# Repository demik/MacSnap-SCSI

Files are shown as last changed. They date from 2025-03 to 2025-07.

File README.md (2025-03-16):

# MacSnap SCSI

The MacSnap SCSI is an upgrade for the Macintosh 512K(e) It includes a SCSI controller and is designed to plug into the ROM slots
It was developed by Dove Computer Corporation. This is a REcreation with a few improvements.

<br />
<br />
<div align = center>
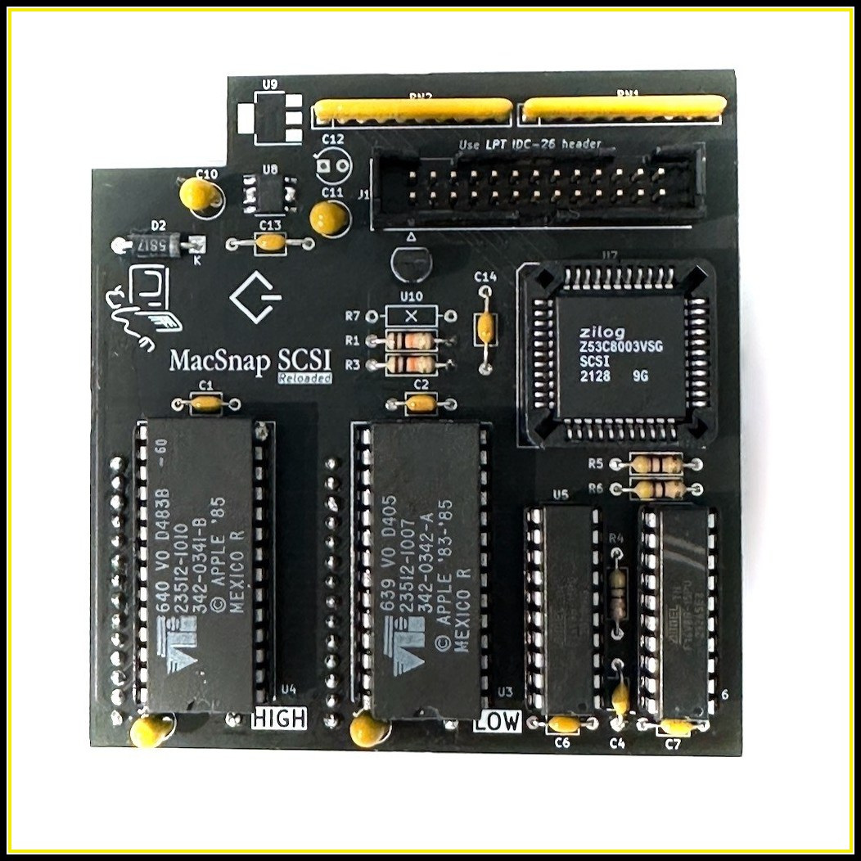
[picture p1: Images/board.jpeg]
board
	
</div>

<br />
<br />
<br />
<br />

## [][Documentation]
- Kikad Files are located [here](EDA/REloaded), as well with building instructions for the REloaded board
- PLD files are located [here](PLD)
- Gerbers files are in the [release section](https://github.com/demik/MacSnap-SCSI/releases/download/v2.1/MacSnap_SCSI_Reloaded_2.1.zip)
- Schematic in PDF form is [here](https://github.com/demik/MacSnap-SCSI/blob/main/EDA/REloaded/MacSnap%20SCSI.pdf)

<!----------------------------------------------------------------------------->

[Documentation]: https://github.com/demik/MacSnap-SCSI/tree/main/EDA/REloaded/README.md

<!-------------------------------[ Buttons ]----------------------------------->

[Button Documentation]: https://img.shields.io/badge/Documentation-FFDD21?style=for-the-badge&logoColor=white&logo=opensourcehardware

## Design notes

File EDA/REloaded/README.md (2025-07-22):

# MacSnap SCSI Reloaded

This is a simple design clone to the original, using mostly all through hole components. It's designed this way to be period correct and easy to build for people who don't like soldering SMD components. The only SMD component is the 2.85V voltage regulator for SCSI termination.
Footprint is very similar. Like the original, the SCSI is provided through a LPT header.

The board has a few improvements:
- provides power to SCSI devices
- active SCSI termination
- voltage supervisor / reset ciruit

This folder contains the source KiKad files for this board.

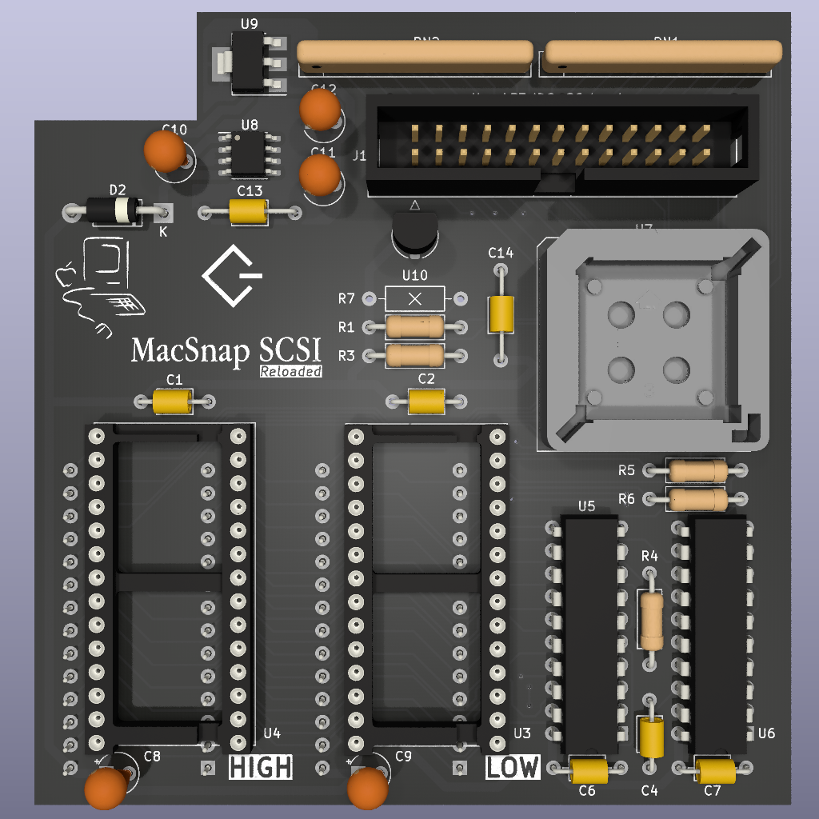
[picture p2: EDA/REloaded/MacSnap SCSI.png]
PCB


## 
### Mandatory

Here is the BOM for the board. Part number are what was tested on prototypes board but you may find alternatives easily, especially resistors and sockets

| Reference(s) | Value | Quantity | Notes | Part number |
|---|---|---|---|---|
| C1-2, C6, C7, C13-14  | 100nF | 6 | Axial ceramic capacitor X7R | Kemet C412C104K5R5TA7200 |
| C4 | 1500pF | 1 | Axial ceramic capacitor X7R 10% | Kemet C410C152K1R5TA |
| C8-11 | 10uF | 4 | Tantalum radial capacitor 2.5mm pitch  | Thomsen 481726 |
| D2 | 1N5817 | 1 | Schottky Diode DO-15 20V | Diotec 1N5817 |
| J1 | 26 pins | 1 | low profile shrouded IDC header | TE Conn 5103309-6 |
| R1, R3 | 10kΩ | 2 | standard 0.25W carbon film resistor | TRU CFR0W4J0103 |
| R4 | 470Ω | 1 | standard 0.25W carbon film resistor | TRU CFR0W4J0471 |
| R5, R6 | 47Ω | 2 | standard 0.25W carbon film resistor | TRU CFR0W4J0470 |
| RN1, RN2 | 110Ω | 2 | 10 pins bussed resistor array | Bourns 4610X-101-111LF |
| U5, U6 | 16V8 | 2 | Programmable Logic Devices 15ns | Microchip ATF16V8B-15PU  |
| U7 | 53C80 | 1 | SCSI Interface IC 3MB/SEC CMOS SCSI I  | Zilog Z53C8003VSG |
| U8 | LDO | 1 | 800mA SCSI-5 Active Terminator | onsemi MC34268DR2G |
| U10 | RESET | 1 | Supervisory Circuits 5V EconoReset | DS1233D-15+ |
| - | LPT | 1 | Parallel DB25 Female LPT to IDC 26-pin | ?? eBay / Amazon |
| - | 14 pins | 4 | Machine Pin break away header | ?? eBay / Amazon |
| Socket | DIP-20 | 2 | THT DIP-20 socket | TRU TC-A 20-LC-TT-203 |
| Socket | DIP-28 | 2 | THT DIP-28 socket | TRU TC-A 28-LC-TT-203 |
| Socket | PLCC-44 | 1 | THT PLCC-44 socket | TRU TC-A-CCS 044-Z-T-203 |

Using sockets is recommended because it will allow you to reclaim both ROMs (to put back into factory) and PLDs

### Alternate

Both the 53C80 SCSI chip and MC34268 are obsolete components. NCR5380 in PLCC package is a working substitute. As for the active terminator LDO, there is an alternate build which consist of the following components:

| Reference(s) | Value | Quantity | Notes | Part number |
|---|---|---|---|---|
| U9 | LDO | 1 | LDO Voltage Regulators 800mA 2.85V | A.D. LT1117CST-2.85 |
| C12 | 10uF | 1 | Tantalum radial capacitor 2.5mm pitch  | Thomsen 481726 |

When the LT1117CST build variant is used, do not populate U8

## 

PCB is 2 layers, the gerbers are avaible in the [release section](https://github.com/demik/MacSnap-SCSI/releases/download/v2.1/MacSnap_SCSI_Reloaded_2.1.zip)
You should be able to use any mainstream PCB manufacturer. Nothing special about this PCB, thickness should be 1.6mm

On JLCPCB, select _Create 2D barcode (Serial Number)_ to the option _Remove Order Number_. Others options to set:
- Printing: 2D barcode Only
- Code Type: QR Code
- Serial Number: MACSNAPSCSI
- QR Code Size: 10mm * 10mm
- QR Code Position: Specify Position

### Assembling

Building is straightworfard. You will need to start with the machine pin headers, then the following order is recommended:
- PDIP sockets
- axial resistors, axial capacitors
- resistors networks
- PLCC socket
- IDC header
- anything else left

### PLDs

You will need the following .jed files to program both ATF with this board:
- [DOV1b](../../PLD/DOV1B.jed) as DOV1b
- [DOV2_low](../../PLD/DOV2_low.jed) as DOV2

A TL866 II or T48 can program ATF16V8Bs just fine. Avoid ATF16V8BQL or ATF16V8C as this has not been tested and might lead into issues

### ROMs

Using real OEM ROMs is recommended. Replica ROMs do have different access timings, source and sink power capabilities, and thus may not work well with the MacSnap SCSI.
The following OEM sets have been tested without issues: 
- 342-0341-B & 342-0342-A
- 342-0341-C + 342-0342-B

<!-------------------------------[ Buttons ]----------------------------------->

[Button BOM]: https://img.shields.io/badge/BOM-FFDD21?style=for-the-badge&logoColor=white&logo=BookStack
[Button Building]: https://img.shields.io/badge/Building-FFDD21?style=for-the-badge&logoColor=white&logo=opensourcehardware

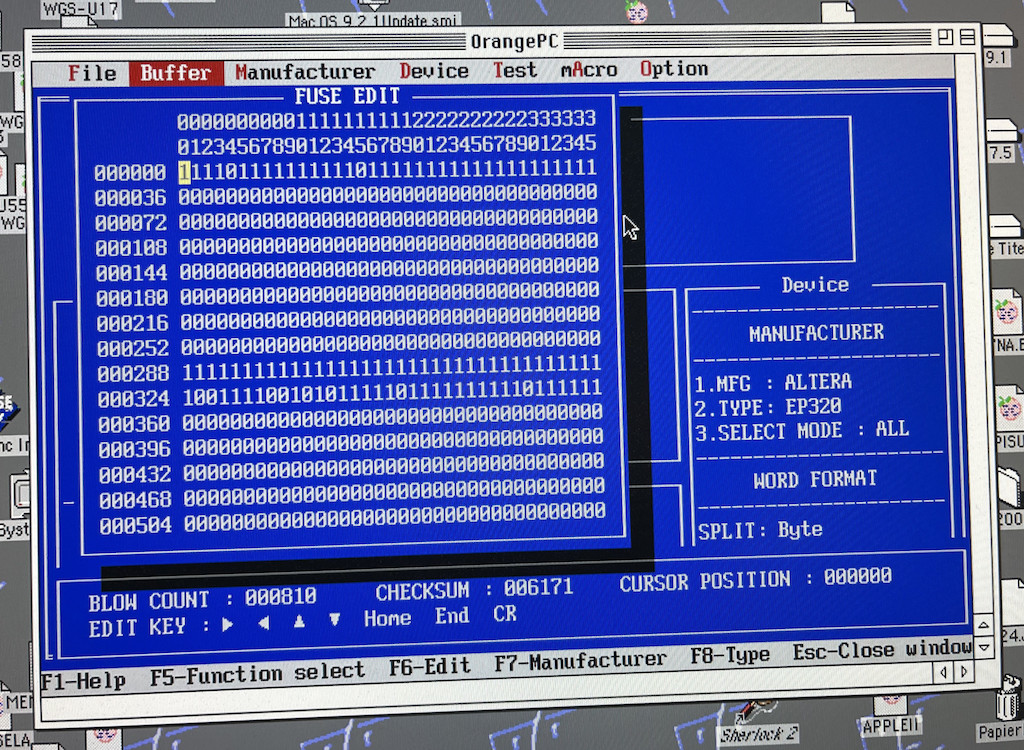
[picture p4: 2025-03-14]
Images/dump.jpeg

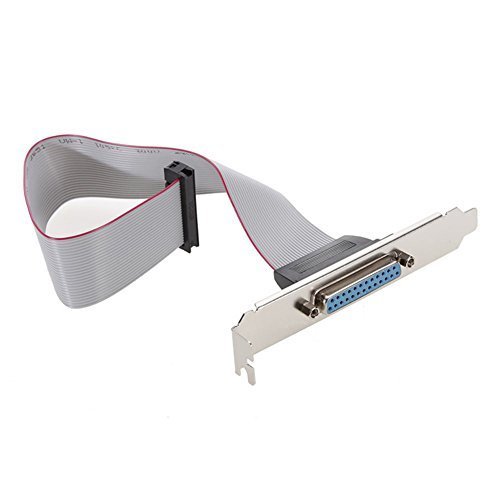
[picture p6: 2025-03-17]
Images/header.jpeg

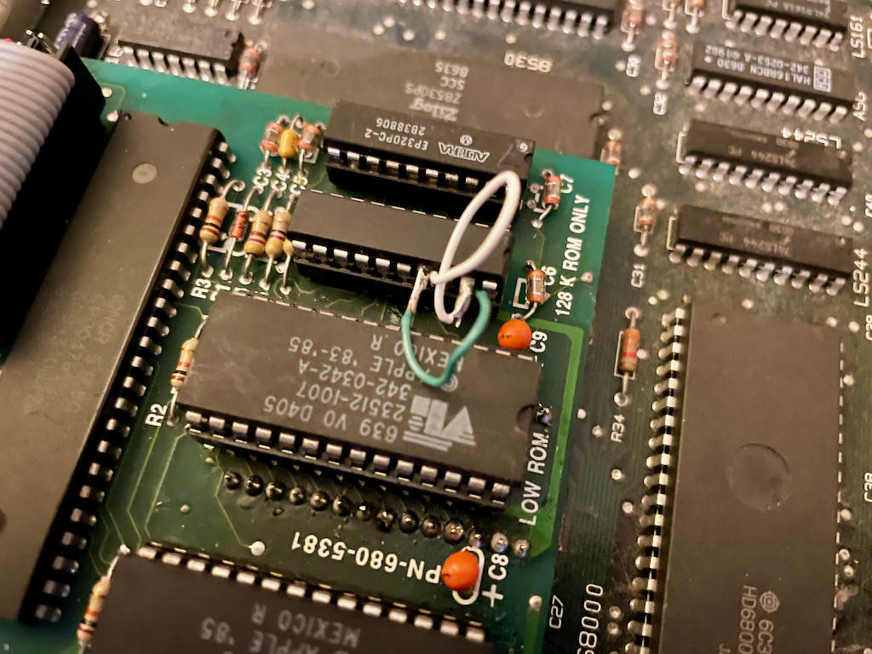
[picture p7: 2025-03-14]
PLD/DOV1b_bodge.png

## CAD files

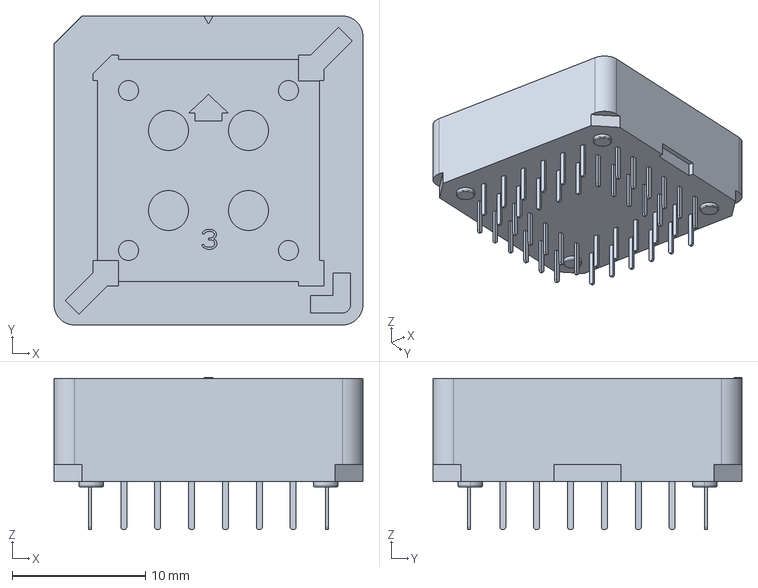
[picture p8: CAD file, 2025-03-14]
EDA/REloaded/54020-44030LF.stp
23.2 x 23.2 x 11.4 mm

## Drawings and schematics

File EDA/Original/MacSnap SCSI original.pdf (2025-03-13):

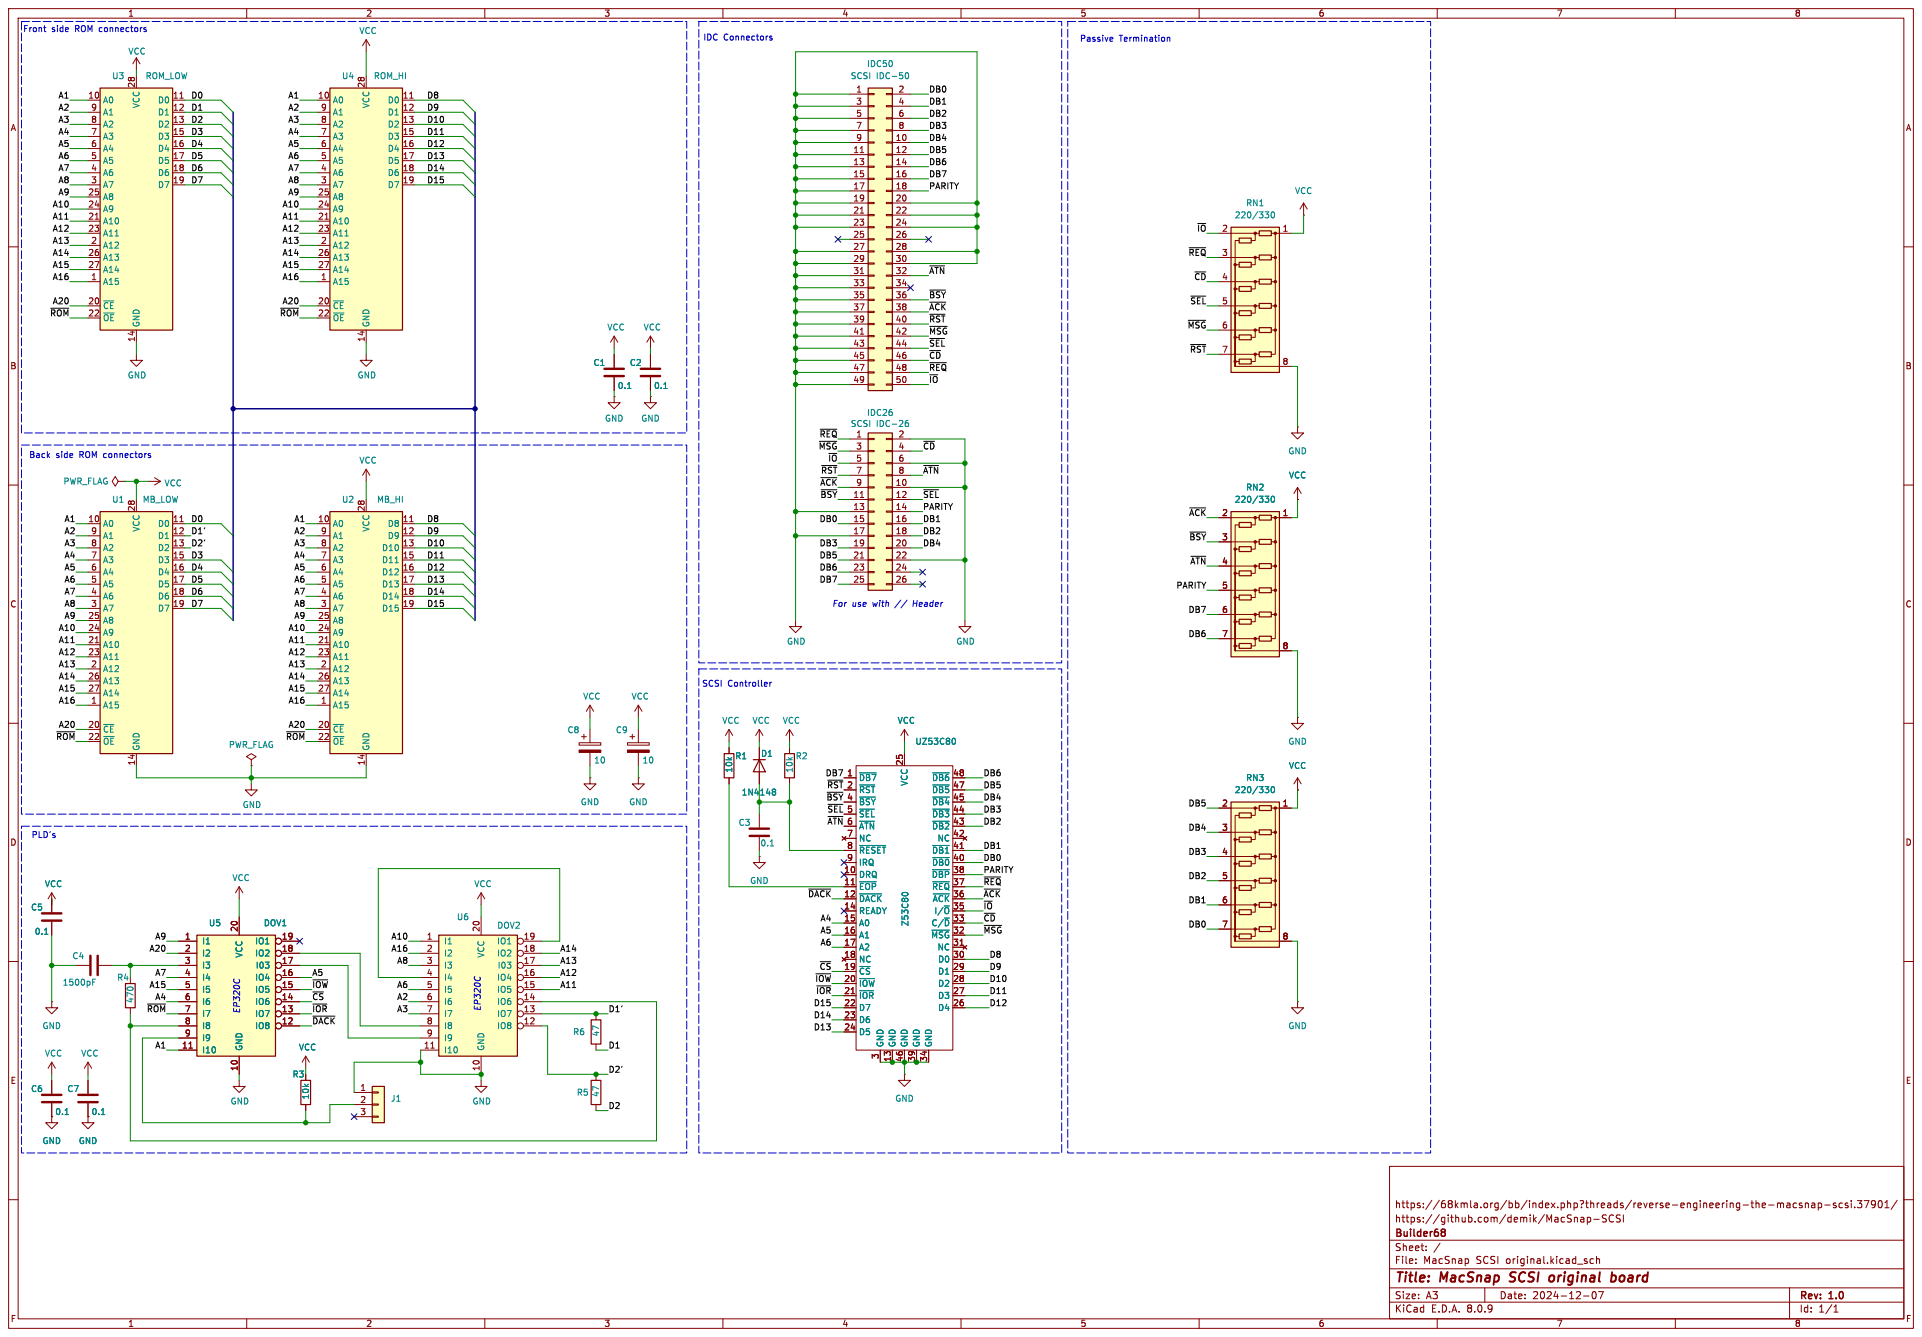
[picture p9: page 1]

Front side ROM connectors

PLD's Back side ROM connectors

~{DB5}47 ~{DB6}48 ~{SEL} 5 ~{ATN} 6 NC 7 ~{RESET} 8
~{RST}
I/~{O}35 ~{ACK} 36 ~{REQ} 37 ~{DBP}38 GND 39

https://68kmla.org/bb/index.php?threads/reverse-engineering-the-macsnap-scsi.37901/ GND

https://github.com/demik/MacSnap-SCSI

Id: 1/1 Title: MacSnap SCSI original board

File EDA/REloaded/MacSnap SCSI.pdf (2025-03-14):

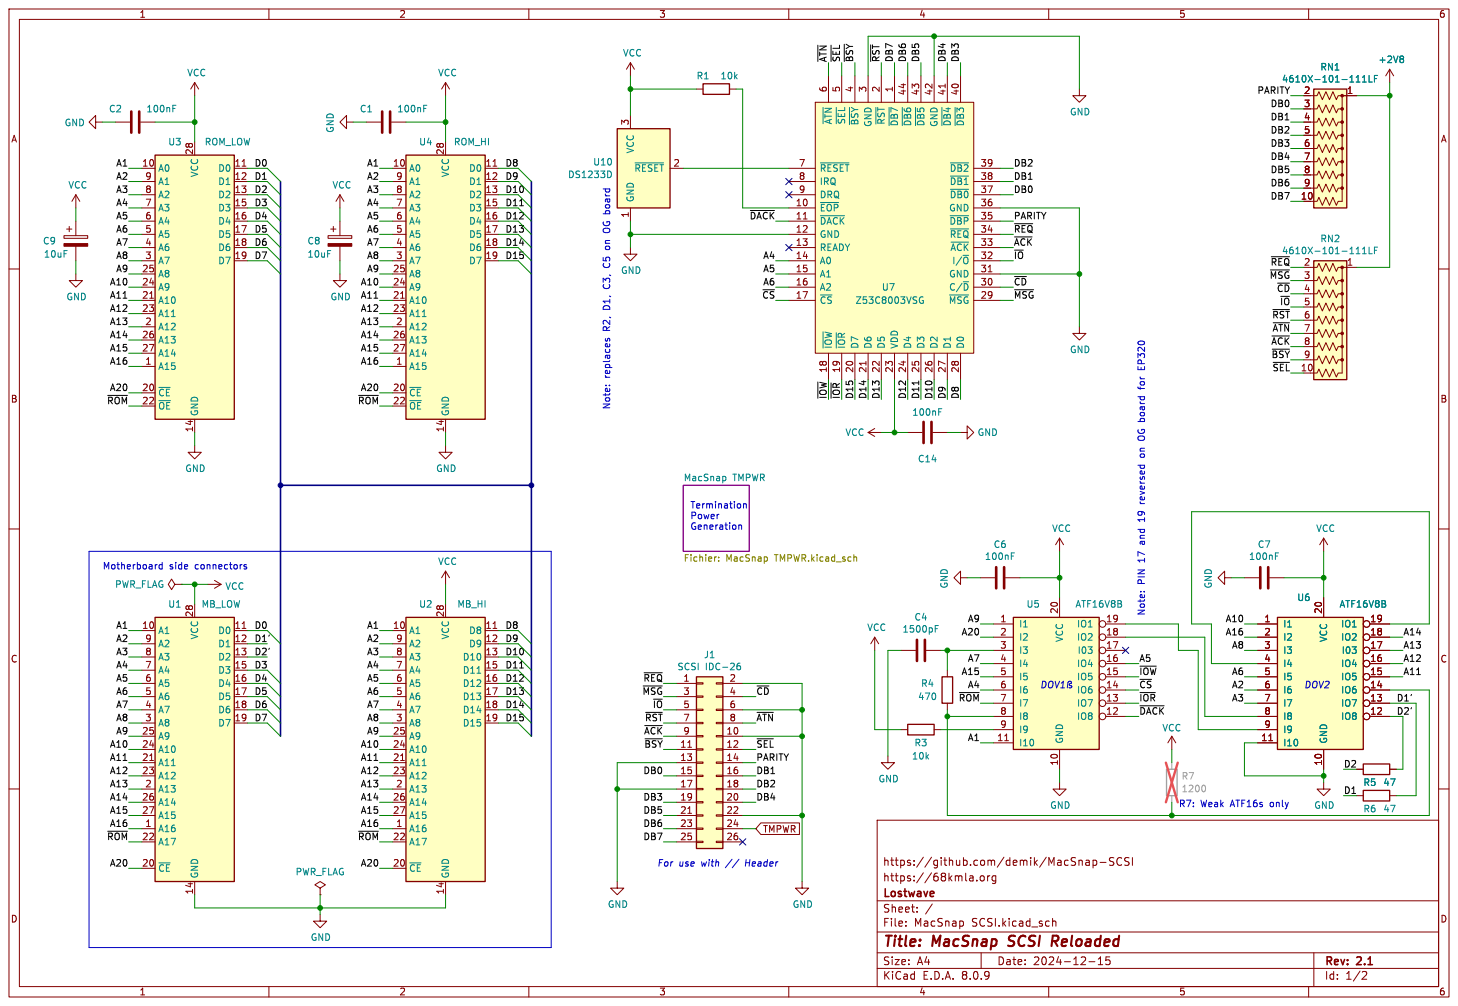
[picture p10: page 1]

https://github.com/demik/MacSnap-SCSI
https://68kmla.org

Id: 1/2 Title: MacSnap SCSI Reloaded

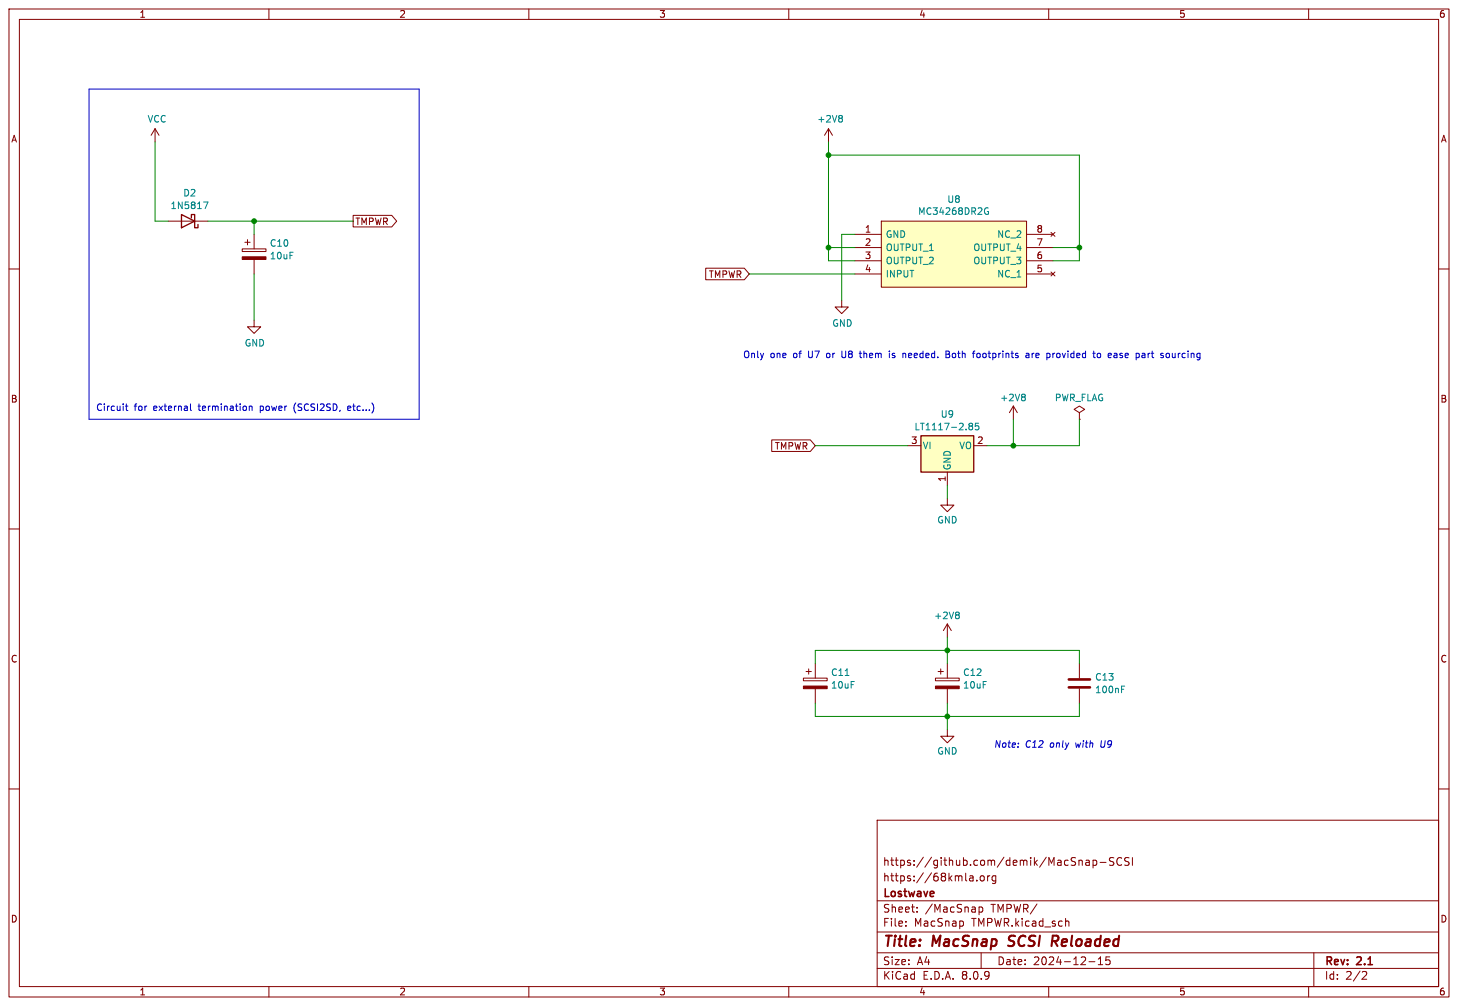
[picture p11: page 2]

https://github.com/demik/MacSnap-SCSI
https://68kmla.org

Id: 2/2 Title: MacSnap SCSI Reloaded

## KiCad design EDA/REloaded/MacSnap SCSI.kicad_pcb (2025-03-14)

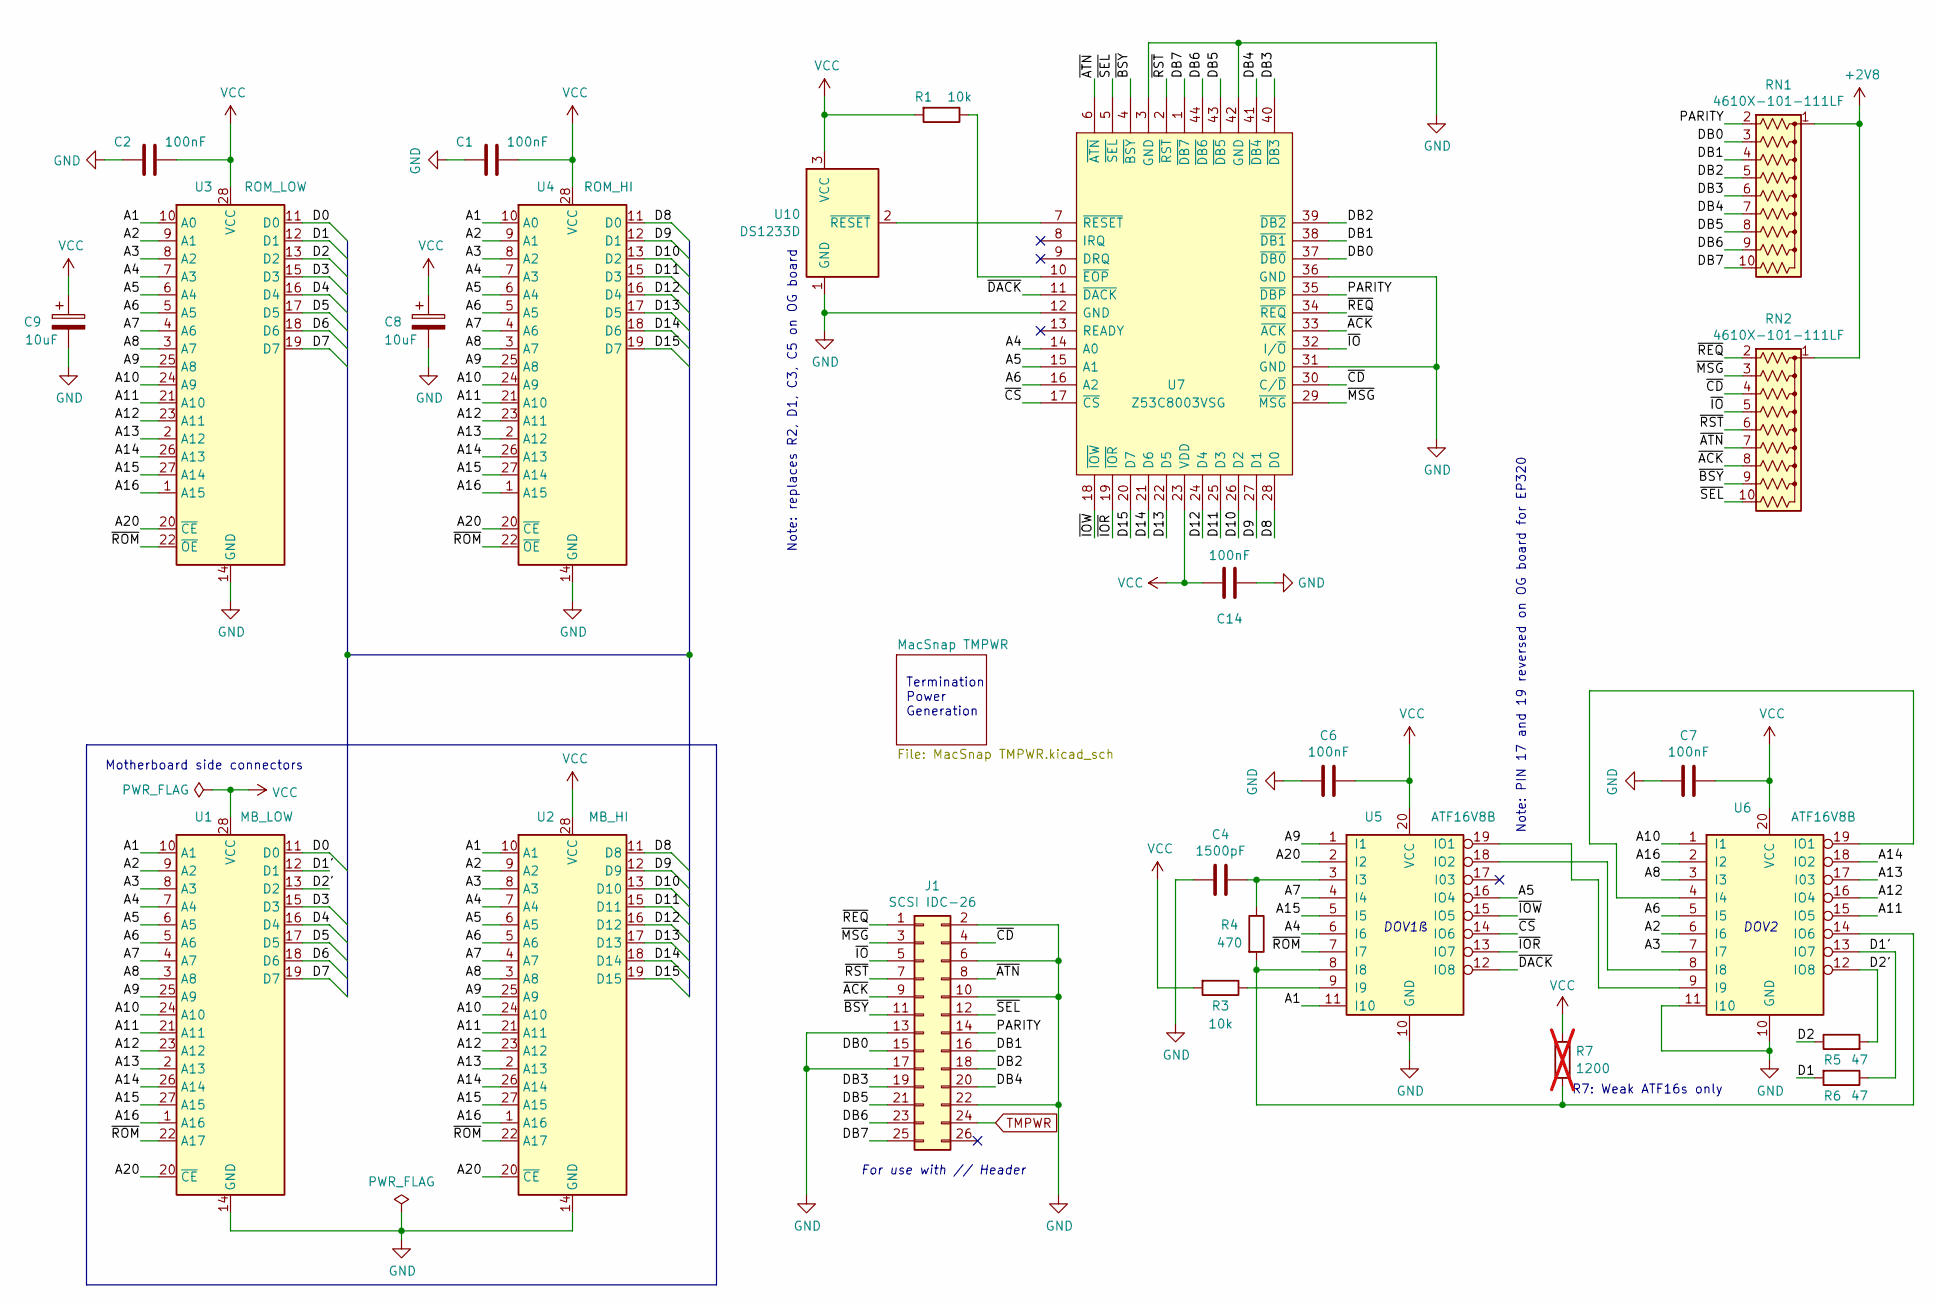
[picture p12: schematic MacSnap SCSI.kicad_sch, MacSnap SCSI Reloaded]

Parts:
C1, C2, C6, C7: 100nF; C_Axial_L3.8mm_D2.6mm_P7.50mm_Horizontal
C4: 1500pF; C_Axial_L3.8mm_D2.6mm_P7.50mm_Horizontal
C8, C9: 10uF; CP_Radial_Tantal_D4.5mm_P2.50mm
C14: 100nF; C_Axial_L3.8mm_D2.6mm_P10.00mm_Horizontal
J1: SCSI IDC-26; IDC-Header_2x13_P2.54mm_Vertical
R1, R3: 10k; R_Axial_DIN0207_L6.3mm_D2.5mm_P10.16mm_Horizontal
R4: 470; R_Axial_DIN0207_L6.3mm_D2.5mm_P10.16mm_Horizontal
R5, R6: 47; R_Axial_DIN0207_L6.3mm_D2.5mm_P10.16mm_Horizontal
R7: 1200; R_Axial_DIN0207_L6.3mm_D2.5mm_P10.16mm_Horizontal; not fitted
RN1, RN2: 4610X-101-111LF; R_Array_SIP10
U1: MB_LOW; DIP-28_W15.24mm_Piggy
U2: MB_HI; DIP-28_W15.24mm_Piggy
U3: ROM_LOW; DIP-28_W15.24mm_Socket
U4: ROM_HI; DIP-28_W15.24mm_Socket
U5, U6: ATF16V8B; DIP-20_W7.62mm
U7: Z53C8003VSG; PLCC-44_THT-Socket; Mouser Part Number 692-Z53C8003VSG
U10: DS1233D; TO-92_HandSolder

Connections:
+2V8: RN1.1 (common), RN2.1 (common); also elsewhere on the board
/A1: U1.10 (A1), U2.10 (A1), U3.10 (A0), U4.10 (A0), U5.11 (I10)
/A2: U1.9 (A2), U2.9 (A2), U3.9 (A1), U4.9 (A1), U6.6 (I6)
/A3: U1.8 (A3), U2.8 (A3), U3.8 (A2), U4.8 (A2), U6.7 (I7)
/A4: U1.7 (A4), U2.7 (A4), U3.7 (A3), U4.7 (A3), U5.6 (I6), U7.14 (A0)
/A5: U1.6 (A5), U2.6 (A5), U3.6 (A4), U4.6 (A4), U5.16 (IO4), U7.15 (A1)
/A6: U1.5 (A6), U2.5 (A6), U3.5 (A5), U4.5 (A5), U6.5 (I5), U7.16 (A2)
/A7: U1.4 (A7), U2.4 (A7), U3.4 (A6), U4.4 (A6), U5.4 (I4)
/A8: U1.3 (A8), U2.3 (A8), U3.3 (A7), U4.3 (A7), U6.3 (I3)
/A9: U1.25 (A9), U2.25 (A9), U3.25 (A8), U4.25 (A8), U5.1 (I1)
/A10: U1.24 (A10), U2.24 (A10), U3.24 (A9), U4.24 (A9), U6.1 (I1)
/A11: U1.21 (A11), U2.21 (A11), U3.21 (A10), U4.21 (A10), U6.15 (IO5)
/A12: U1.23 (A12), U2.23 (A12), U3.23 (A11), U4.23 (A11), U6.16 (IO4)
/A13: U1.2 (A13), U2.2 (A13), U3.2 (A12), U4.2 (A12), U6.17 (I03)
/A14: U1.26 (A14), U2.26 (A14), U3.26 (A13), U4.26 (A13), U6.18 (IO2)
/A15: U1.27 (A15), U2.27 (A15), U3.27 (A14), U4.27 (A14), U5.5 (I5)
/A16: U1.1 (A16), U2.1 (A16), U3.1 (A15), U4.1 (A15), U6.2 (I2)
/A20: U1.20 (~CE), U2.20 (~CE), U3.20 (~CE), U4.20 (~CE), U5.2 (I2)
/D0: U1.11 (D0), U3.11 (D0)
/D1: R6.2, U3.12 (D1)
/D1': R6.1, U1.12 (D1), U6.13 (IO7)
/D2: R5.1, U3.13 (D2)
/D2': R5.2, U1.13 (D2), U6.12 (IO8)
/D3: U1.15 (D3), U3.15 (D3)
/D4: U1.16 (D4), U3.16 (D4)
/D5: U1.17 (D5), U3.17 (D5)
/D6: U1.18 (D6), U3.18 (D6)
/D7: U1.19 (D7), U3.19 (D7)
/D8: U2.11 (D8), U4.11 (D0), U7.28 (D0)
/D9: U2.12 (D9), U4.12 (D1), U7.27 (D1)
/D10: U2.13 (D10), U4.13 (D2), U7.26 (D2)
/D11: U2.15 (D11), U4.15 (D3), U7.25 (D3)
/D12: U2.16 (D12), U4.16 (D4), U7.24 (D4)
/D13: U2.17 (D13), U4.17 (D5), U7.22 (D5)
/D14: U2.18 (D14), U4.18 (D6), U7.21 (D6)
/D15: U2.19 (D15), U4.19 (D7), U7.20 (D7)
/DB0: J1.15, RN1.3 (R2), U7.37 (~DB0)
/DB1: J1.16, RN1.4 (R3), U7.38 (~DB1)
/DB2: J1.18, RN1.5 (R4), U7.39 (~DB2)
/DB3: J1.19, RN1.6 (R5), U7.40 (~DB3)
/DB4: J1.20, RN1.7 (R6), U7.41 (~DB4)
/DB5: J1.21, RN1.8 (R7), U7.43 (~DB5)
/DB6: J1.23, RN1.9 (R8), U7.44 (~DB6)
/DB7: J1.25, RN1.10 (R9), U7.1 (~DB7)
/PARITY: J1.14, RN1.2 (R1), U7.35 (~DBP)
/~ACK: J1.9, RN2.8 (R7), U7.33 (~ACK)
/~ATN: J1.8, RN2.7 (R6), U7.6 (~ATN)
/~BSY: J1.11, RN2.9 (R8), U7.4 (~BSY)
/~CD: J1.4, RN2.4 (R3), U7.30 (C/~D)
/~CS: U5.14 (IO6), U7.17 (~CS)
/~DACK: U5.12 (IO8), U7.11 (~DACK)
/~IOR: U5.13 (IO7), U7.19 (~IOR)
/~IOW: U5.15 (IO5), U7.18 (~IOW)
/~IO: J1.5, RN2.5 (R4), U7.32 (I/~O)
/~MSG: J1.3, RN2.3 (R2), U7.29 (~MSG)
/~REQ: J1.1, RN2.2 (R1), U7.34 (~REQ)
/~ROM: U1.22 (A17), U2.22 (A17), U3.22 (~OE), U4.22 (~OE), U5.7 (I7)
/~RST: J1.7, RN2.6 (R5), U7.2 (~RST)
/~SEL: J1.12, RN2.10 (R9), U7.5 (~SEL)
GND: C1.2, C2.2, C4.2, C6.2, C7.2, C8.2, C9.2, C14.2, J1.2, J1.6, J1.10, J1.13, J1.17, J1.22, U1.14 (GND), U2.14 (GND), U3.14 (GND), U4.14 (GND), U5.10 (GND), U6.10 (GND), U6.11 (I10), U7.3 (GND), U7.12 (GND), U7.31 (GND), U7.36 (GND), U7.42 (GND), U10.1 (GND); also elsewhere on the board
unnamed: C4.1, R4.1, U5.3 (I3)
unnamed: R4.2, R7.2, U5.8 (I8), U6.14 (IO6)
unnamed: R3.1, U5.9 (I9)
unnamed: U5.19 (IO1), U6.9 (I9)
unnamed: U5.18 (IO2), U6.8 (I8)
unnamed: U6.4 (I4), U6.19 (IO1)
unnamed: R1.1, U7.10 (~EOP)
unnamed: U7.7 (~RESET), U10.2 (~RESET)
TMPWR: J1.24; also elsewhere on the board
VCC: C1.1, C2.1, C6.1, C7.1, C8.1, C9.1, C14.1, R1.2, R3.2, R7.1, U1.28 (VCC), U2.28 (VCC), U3.28 (VCC), U4.28 (VCC), U5.20 (VCC), U6.20 (VCC), U7.23 (VDD), U10.3 (VCC); also elsewhere on the board

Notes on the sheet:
R7: Weak ATF16s only
Termination Power Generation
DOV1ß
Note: replaces R2, D1, C3, C5 on OG board
Motherboard side connectors
For use with // Header
Note: PIN 17 and 19 reversed on OG board for EP320
DOV2

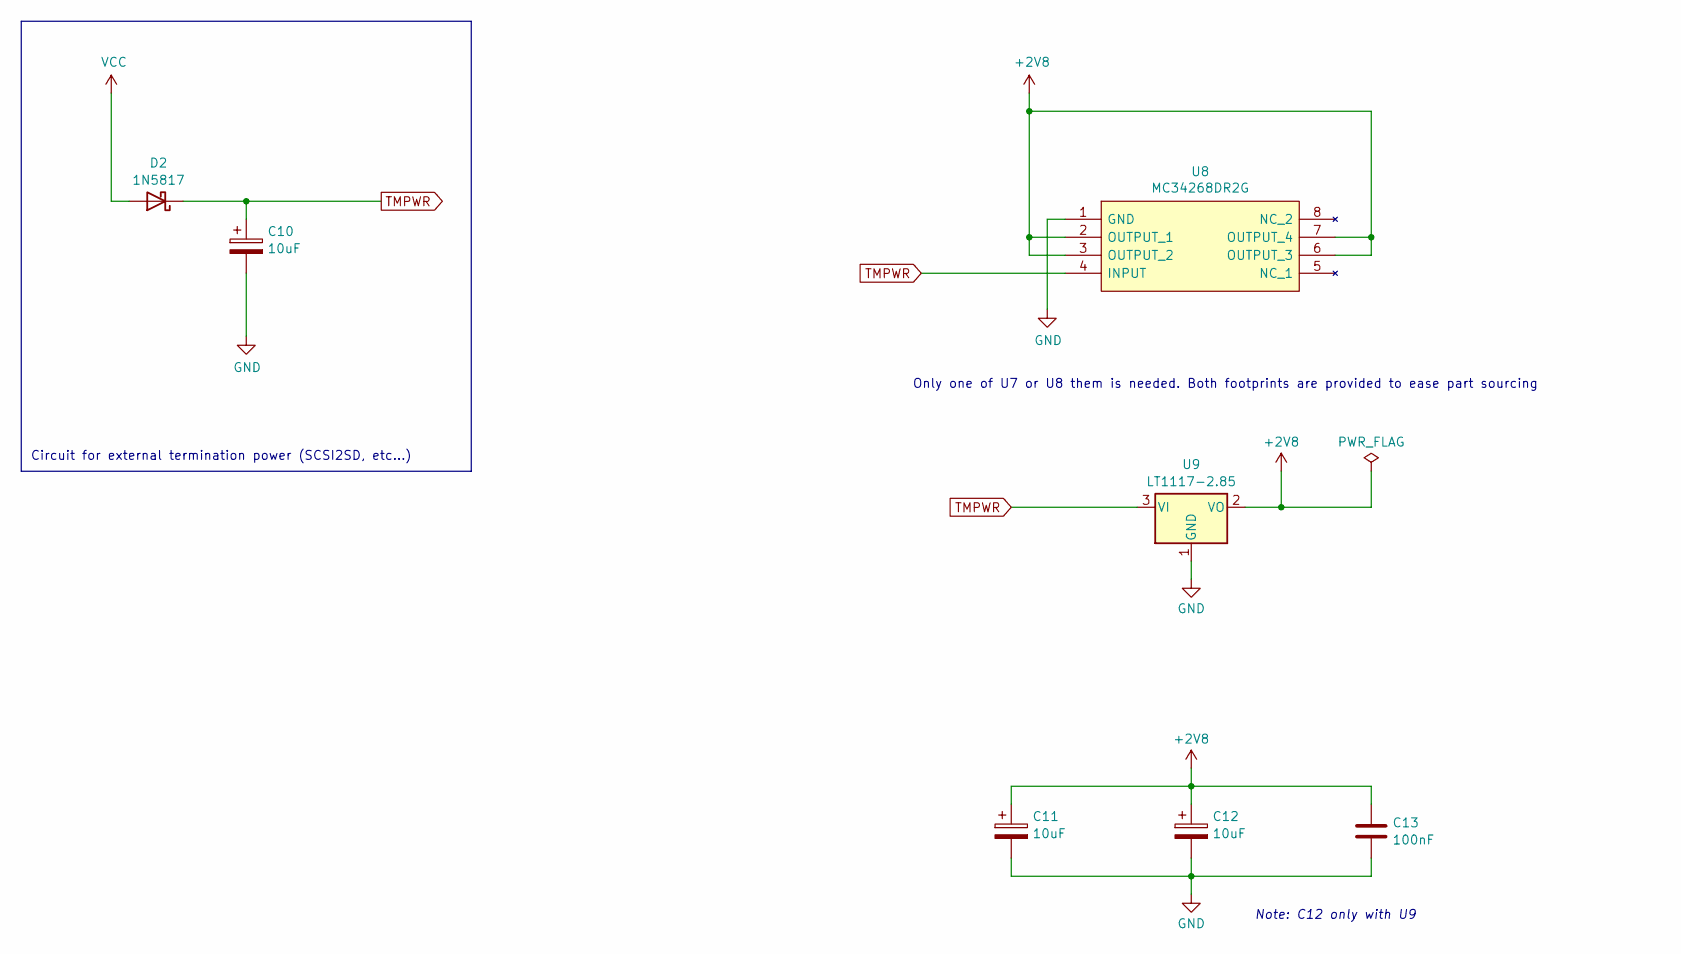
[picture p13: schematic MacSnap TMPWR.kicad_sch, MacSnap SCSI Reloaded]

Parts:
C10, C11, C12: 10uF; CP_Radial_Tantal_D4.5mm_P2.50mm
C13: 100nF; C_Axial_L3.8mm_D2.6mm_P10.00mm_Horizontal
D2: 1N5817; D_DO-41_SOD81_P10.16mm_Horizontal
U8: MC34268DR2G; SOIC-8_3.9x4.9mm_P1.27mm; Mouser Part Number 863-MC34268DR2G
U9: LT1117-2.85; SOT-223-3_TabPin2

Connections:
+2V8: C11.1, C12.1, C13.1, U8.2 (OUTPUT_1), U8.3 (OUTPUT_2), U8.6 (OUTPUT_3), U8.7 (OUTPUT_4), U9.2 (VO); also elsewhere on the board
GND: C10.2, C11.2, C12.2, C13.2, U8.1 (GND), U9.1 (GND); also elsewhere on the board
TMPWR: C10.1, D2.1 (K), U8.4 (INPUT), U9.3 (VI); also elsewhere on the board
VCC: D2.2 (A); also elsewhere on the board

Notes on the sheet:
Circuit for external termination power (SCSI2SD, etc…)
Only one of U7 or U8 them is needed. Both footprints are provided to ease part sourcing
Note: C12 only with U9

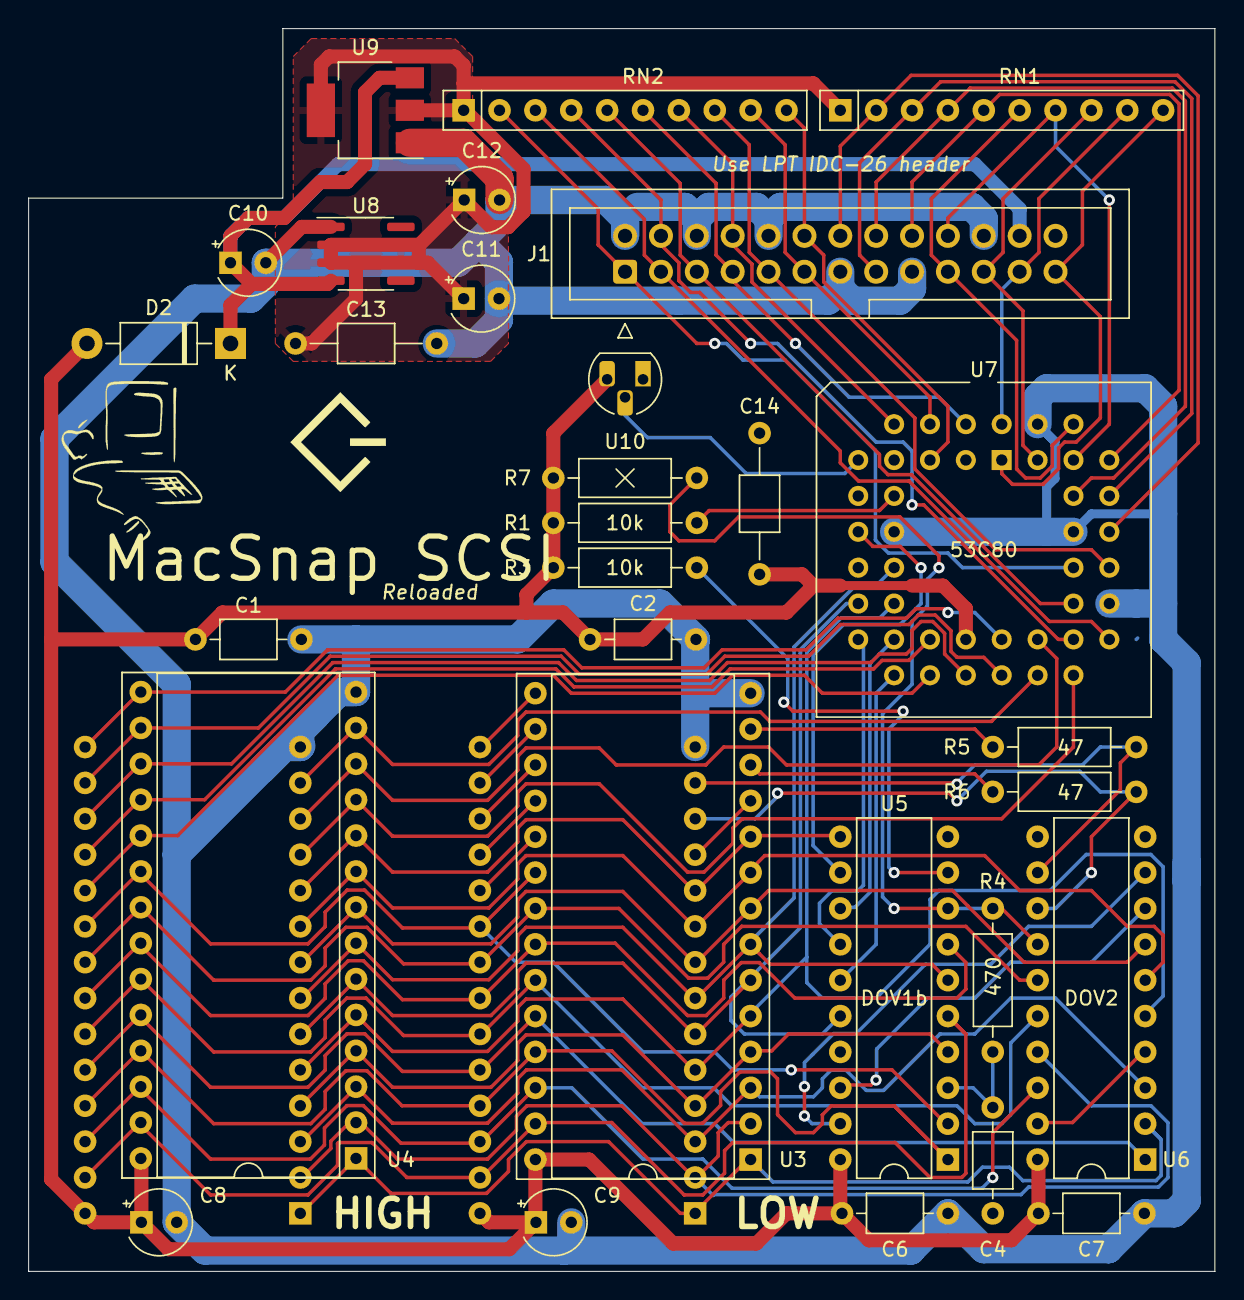
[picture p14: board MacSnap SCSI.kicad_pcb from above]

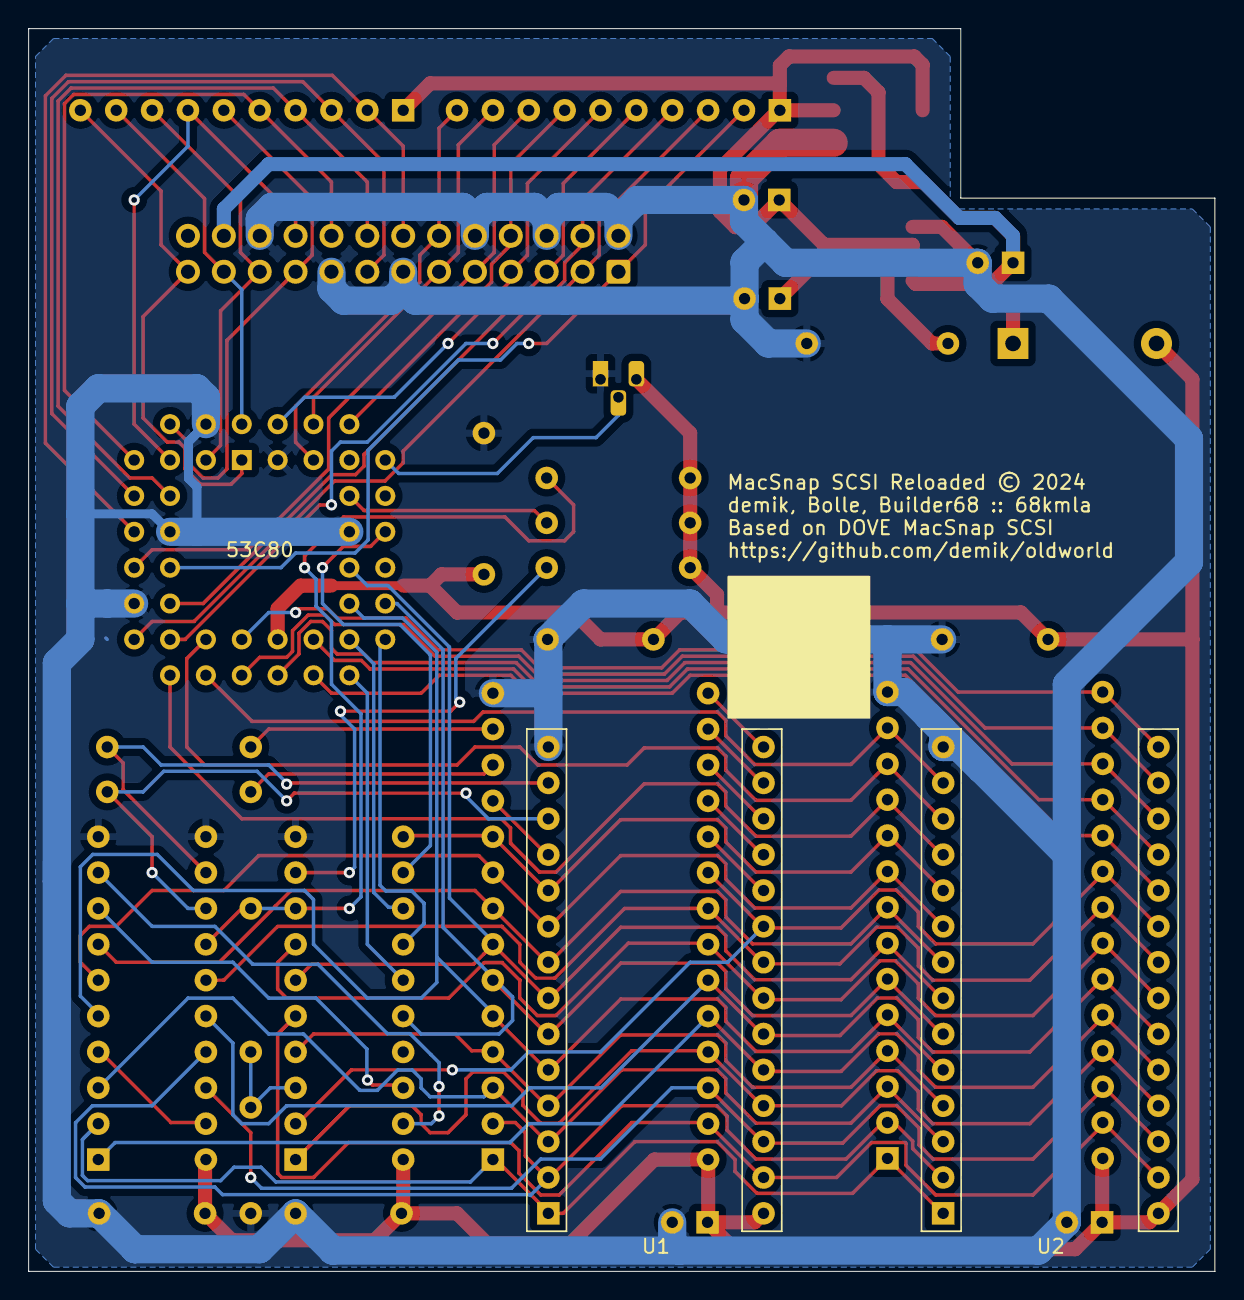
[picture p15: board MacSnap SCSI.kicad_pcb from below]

Board: 2 copper layers, 84.0 x 88.0 mm, 32 parts (2 on the bottom side), 70 nets.

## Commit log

2025-03-13 added original schematics by Builder68
    [MacSnap SCSI original.kicad_sch]
2025-03-14 Initial REloaded public release
    [54020-44030LF.stp, MacSnap SCSI.kicad_pcb, MacSnap SCSI.kicad_sch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]
2025-03-16 fixed building button
2025-03-17 added machine pin headers picture

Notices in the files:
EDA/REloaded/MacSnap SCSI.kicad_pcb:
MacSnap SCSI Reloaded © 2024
